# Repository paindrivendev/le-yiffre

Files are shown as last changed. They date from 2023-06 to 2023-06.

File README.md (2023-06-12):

# Le Yiffre

Le Yiffre is a modified hotswap Le Chiffre pcb as an experimental design with different thumb clusters.Thanks to tominabox1 for creating [Le Chiffre Keyboard](https://github.com/tominabox1/Le-Chiffre-Keyboard) and making it open source.

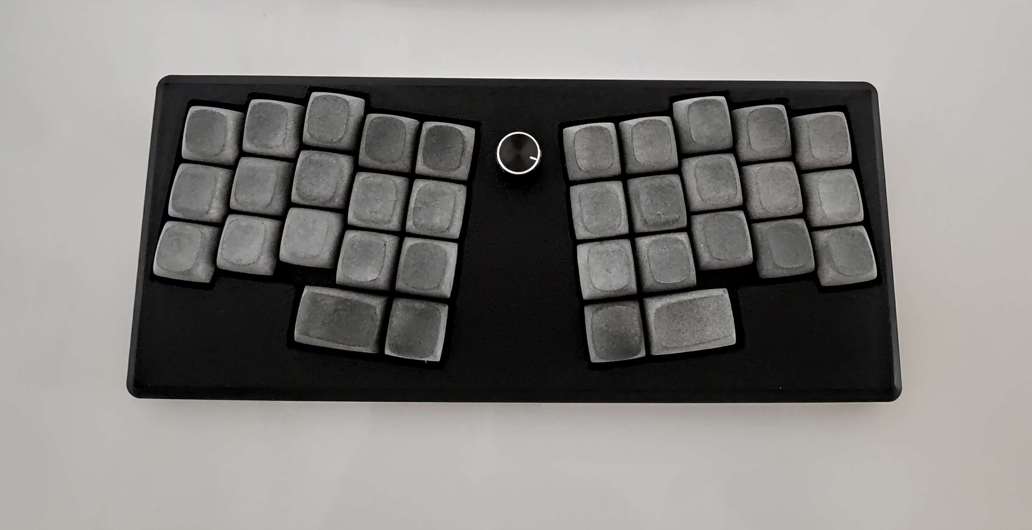
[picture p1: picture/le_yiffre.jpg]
Le Yiffre Keyboard


## Description

PCB, 3d case and switch plates tested and works fine. Building one is your own
risk.

## QMK Configuration

Works with le chiffre qmk config.

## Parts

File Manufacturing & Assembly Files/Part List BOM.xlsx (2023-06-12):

Item | Qty | Reference(s) | Value | Footprint | JLCPCB Part# | Weblink | Column1
1 | 5 | C1, C2, C4, C5, C7 | 100nf | Ahsan Libs:C_0603_1608Metric | C14663 | https://lcsc.com/product-detail/Multilayer-Ceramic-Capacitors-MLCC-SMD-SMT_YAGEO-CC0603KRX7R9BB104_C14663.html
2 | 1 | C8 | 4.7uf | Ahsan Libs:C_0603_1608Metric | C19666 | https://www.lcsc.com/product-detail/Multilayer-Ceramic-Capacitors-MLCC-SMD-SMT_Samsung-Electro-Mechanics-CL10A475KO8NNNC_C19666.html
3 | 1 | C9 | 1uf | Ahsan Libs:C_0603_1608Metric | C15849 | https://lcsc.com/product-detail/Multilayer-Ceramic-Capacitors-MLCC-SMD-SMT_Samsung-Electro-Mechanics-CL10A105KB8NNNC_C15849.html
4 | 2 | C10, C11 | 22pf | Ahsan Libs:C_0603_1608Metric | C1653 | https://lcsc.com/product-detail/Multilayer-Ceramic-Capacitors-MLCC-SMD-SMT_Samsung-Electro-Mechanics-CL10C220JB8NNNC_C1653.html
5 | 34 | D1, D2, D3, D4, D5, D6, D7, D8, D9, D10, D11, D12, D13, D14, D15, D16, D17, D18, D19, D20, D21, D22, D23, D24, D25, D26, D27, D28, D29, D30, D31, D32, D33, D34, D35 | 1N4148 | Ahsan Libs:D_SOD-123 | C81598 | https://lcsc.com/product-detail/Switching-Diode_ST-Semtech-1N4148W_C81598.html
6 | 11 | D101, D102, D103, D104, D105, D106, D107, D108, D109, D110, D111 | WS2812B | LED_SMD:LED_WS2812B_PLCC4_5.0x5.0mm_P3.2mm | C2761795 | https://www.lcsc.com/product-detail/Light-Emitting-Diodes-LED_Worldsemi-WS2812B-B-T_C2761795.html
7 | 1 | ESD2 | PRTR5V0U2X | Ahsan Libs:PRTR5V0U2X | C2827688 | https://lcsc.com/product-detail/ESD-Protection-Devices_TECH-PUBLIC-PRTR5V0U2X_C2827688.html
8 | 1 | OLED1 | Screw_Terminal_01x04 | Ahsan Libs:SSD1306-0.91-OLED-4pin-128x32 | C5116530 | https://www.lcsc.com/product-detail/Female-Headers_ZHOURI-PM2-54-1-4_C5116530.html
9 | 1 | P1 | LED | Ahsan Libs:LED_0603_1608Metric | C72041 | https://lcsc.com/product-detail/Light-Emitting-Diodes-LED_Everlight-Elec-19-217-BHC-ZL1M2RY-3T_C72041.html
10 | 2 | R7, R8 | 4.7k | Ahsan Libs:R_0603_1608Metric | C23162 | https://www.lcsc.com/product-detail/Chip-Resistor-Surface-Mount_UNI-ROYAL-Uniroyal-Elec-0603WAF4701T5E_C23162.html
11 | 2 | R11, R12 | 5.1K | Ahsan Libs:R_0603_1608Metric | C23186 | https://lcsc.com/product-detail/Chip-Resistor-Surface-Mount_UNI-ROYAL-Uniroyal-Elec-0603WAF5101T5E_C23186.html
12 | 2 | R14, R17 | 10k | Ahsan Libs:R_0603_1608Metric | C25804 | https://lcsc.com/product-detail/Chip-Resistor-Surface-Mount_UNI-ROYAL-Uniroyal-Elec-0603WAF1002T5E_C25804.html
13 | 1 | R15 | 22 | Ahsan Libs:R_0603_1608Metric | C1203 | https://lcsc.com/product-detail/Chip-Resistor-Surface-Mount_UNI-ROYAL-Uniroyal-Elec-0603WAJ0220T5E_C1203.html
14 | 1 | R16 | 22 | Ahsan Libs:R_0603_1608Metric | C1203 | https://lcsc.com/product-detail/Chip-Resistor-Surface-Mount_UNI-ROYAL-Uniroyal-Elec-0603WAJ0220T5E_C1203.html
15 | 1 | R18 | 470 | Ahsan Libs:R_0603_1608Metric | C23179 | https://lcsc.com/product-detail/Chip-Resistor-Surface-Mount_UNI-ROYAL-Uniroyal-Elec-0603WAF4700T5E_C23179.html
16 | 35 | SW2, SW3, SW4, SW5, SW6, SW7, SW8, SW9, SW10, SW11, SW12, SW13, SW14, SW15, SW16, SW17, SW18, SW19, SW20, SW21, SW22, SW23, SW24, SW25, SW26, SW27, SW28, SW29, SW30, SW31, SW32, SW33, SW34, SW35, SW37 | SW_Push | Ahsan Libs:SW_Hotswap_Kailh_1.00u_rev | C5156480 | https://lcsc.com/product-detail/Mechanical-Keyboard-Shaft_Kailh-CPG151101S11-16_C5156480.html | https://shop.keyboard.io/products/kailh-hotswap-sockets-for-mx-style-keyswitches-x-25
17 | 1 | SW36 | Rotary_Encoder_Switch | Rotary_Encoder:RotaryEncoder_Alps_EC12E-Switch_Vertical_H20mm_CircularMountingHoles | C370992 | https://www.lcsc.com/product-detail/Rotary-Encoders_ALPSALPINE-EC11E153440D_C370992.html
18 | 1 | SWR1 | SW_Push | Ahsan Libs:K2-1187SQ-A4SW-06 | C388295 | https://lcsc.com/product-detail/Tactile-Switches_SHOU-HAN-TS5215A-250gf_C388295.html
19 | 1 | U1 | ATMEGA32U4-MU | Ahsan Libs:ATMEGA32U4-MURr | C112161 | https://lcsc.com/product-detail/ATMEL-AVR_Microchip-Tech-ATMEGA32U4-MU_C112161.html
20 | 1 | USB1 | USB_C_Receptacle_USB2.0 | Ahsan Libs:USB_C_Receptacle_HRO_TYPE-C-31-M-12 | C165948 | https://www.lcsc.com/product-detail/USB-Connectors_Korean-Hroparts-Elec-TYPE-C-31-M-12_C165948.html
21 | 1 | Y2 | Crystal_GND23 | Ahsan Libs:Crystal_SMD_3225-4Pin_3.2x2.5mm | C13738 | https://lcsc.com/product-detail/Crystals_Yangxing-Tech-X322516MLB4SI_C13738.html

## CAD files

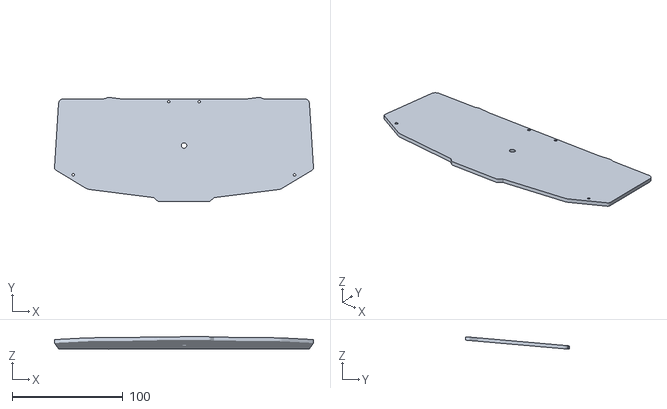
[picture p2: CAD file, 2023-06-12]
p3d_case/Le Chiffre Acylic Bottom stl.stl
234.2 x 94.2 x 11.3

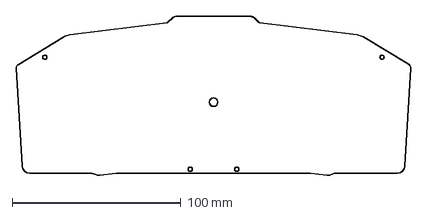
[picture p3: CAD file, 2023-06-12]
p3d_case/Acrylic Bottom Le Chiffre P3D Mod v7.dxf
234.3 x 94.4 mm

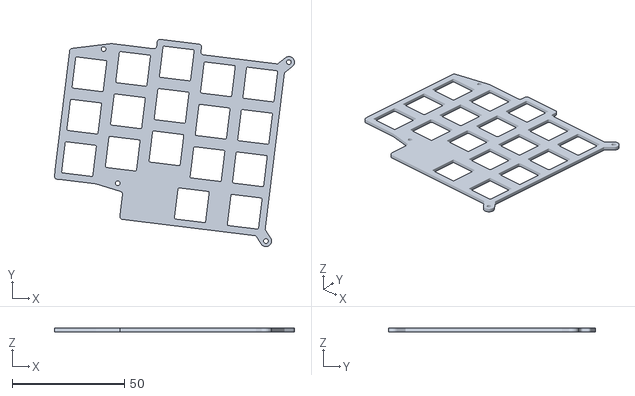
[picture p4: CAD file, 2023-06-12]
p3d_case/swtich_plate_left.stl
107.1 x 92.5 x 1.60

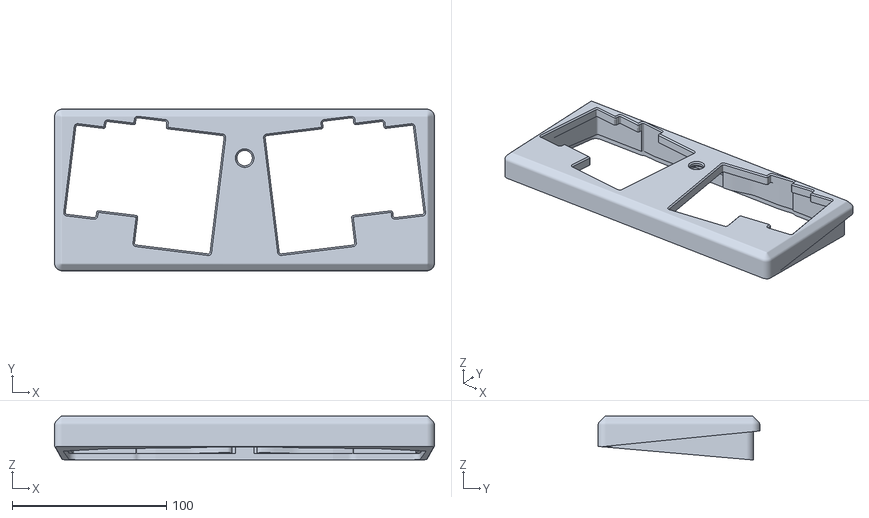
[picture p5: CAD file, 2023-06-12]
p3d_case/top_case.stl
246.4 x 104.8 x 28.5

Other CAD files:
p3d_case/switch_plate_right.stl

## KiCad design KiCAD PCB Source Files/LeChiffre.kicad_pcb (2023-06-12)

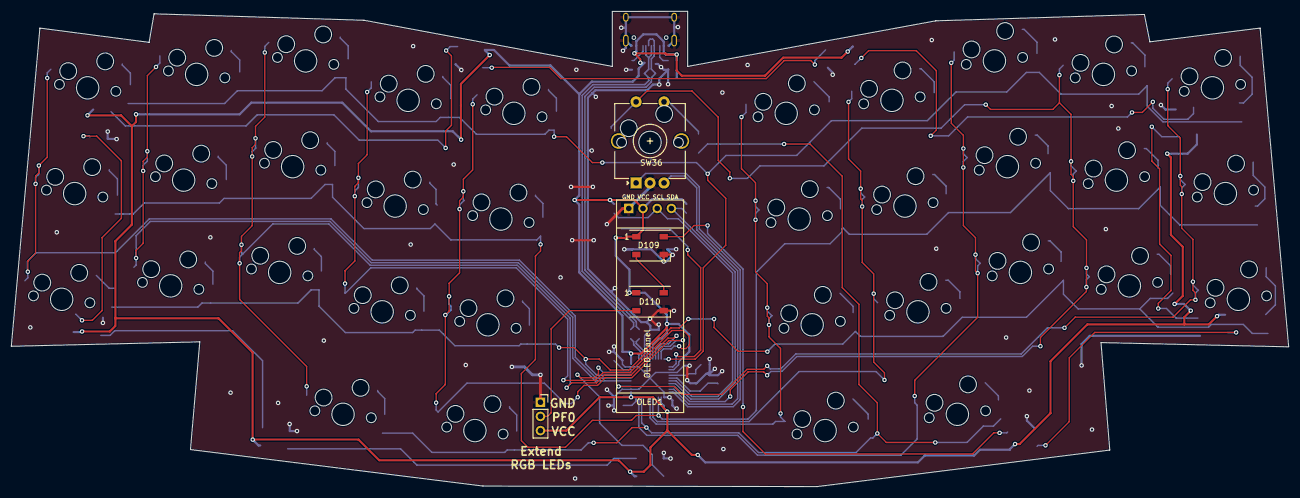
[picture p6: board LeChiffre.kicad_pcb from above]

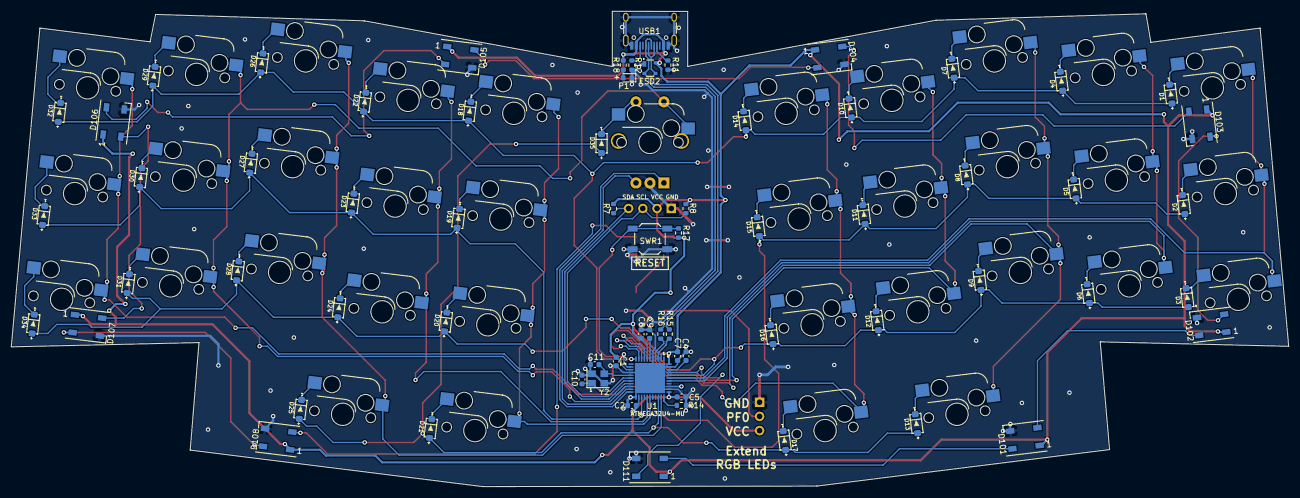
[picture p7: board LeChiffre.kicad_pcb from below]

Board: 2 copper layers, 228.4 x 85.0 mm, 108 parts (103 on the bottom side), 80 nets.

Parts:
C1, C2, C4, C5, C7: 100nf; C_0603_1608Metric
C8: 4.7uf; C_0603_1608Metric
C9: 1uf; C_0603_1608Metric
C10, C11: 22pf; C_0603_1608Metric
D1, D2, D3, D4, D5, D6, D7, D8, D9, D10, D11, D12, D13, D14, D15, D16, D17, D18, D19, D20, D21, D22, D23, D24, D25, D26, D27, D28, D29, D30, D31, D32, D33, D34, D35: 1N4148; D_SOD-123
D101, D102, D103, D104, D105, D106, D107, D108, D109, D110, D111: WS2812B; LED_WS2812B_PLCC4_5.0x5.0mm_P3.2mm
ESD2: PRTR5V0U2X
J1: Conn_01x03_Female; PinSocket_1x03_P2.54mm_Vertical
OLED1: Screw_Terminal_01x04; SSD1306-0.91-OLED-4pin-128x32
P1: LED; LED_0603_1608Metric
R7, R8: 4.7k; R_0603_1608Metric
R11, R12: 5.1K; R_0603_1608Metric
R14, R17: 10k; R_0603_1608Metric
R15, R16: 22; R_0603_1608Metric
R18: 470; R_0603_1608Metric
SW2, SW3, SW4, SW5, SW6, SW7, SW8, SW9, SW10, SW11, SW12, SW13, SW14, SW15, SW16, SW17, SW18, SW19, SW20, SW21, SW22, SW23, SW24, SW25, SW26, SW27, SW28, SW29, SW30, SW31, SW32, SW33, SW34, SW35, SW37: SW_Push; SW_Hotswap_Kailh_1.00u_rev
SW36: Rotary_Encoder_Switch; RotaryEncoder_Alps_EC12E-Switch_Vertical_H20mm_CircularMoun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
SWR1: SW_Push; K2-1187SQ-A4SW-06
U1: ATMEGA32U4-MU; ATMEGA32U4-MURr
USB1: USB_C_Receptacle_USB2.0; USB_C_Receptacle_HRO_TYPE-C-31-M-12
Y2: Crystal_GND23; Crystal_SMD_3225-4Pin_3.2x2.5mm

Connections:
+5V: C1.1, C2.1, C5.1, C7.1, C8.1, D101.1 (VDD), D102.1 (VDD), D103.1 (VDD), D104.1 (VDD), D105.1 (VDD), D106.1 (VDD), D107.1 (VDD), D108.1 (VDD), D109.1 (VDD), D110.1 (VDD), D111.1 (VDD), ESD2.4 (VCC), J1.3 (Pin_1), OLED1.2, R7.2, R8.2, R17.1, R18.2, U1.2 (UVCC), U1.7 (VBUS), U1.14 (VCC_1), U1.24 (AVCC_1), U1.34 (VCC_2), U1.44 (AVCC_2), USB1.A4 (VBUS), USB1.A9 (VBUS), USB1.B4 (VBUS), USB1.B9 (VBUS)
DN: ESD2.3 (I/O2), R15.2, USB1.A7 (D-), USB1.B7 (D-)
DP: ESD2.2 (I/O1), R16.2, USB1.A6 (D+), USB1.B6 (D+)
D_N: R15.1, U1.3 (D-)
D_P: R16.1, U1.4 (D+)
EncA: SW36.A, U1.22 ((XCK1/~CTS)_PD5)
EncB: SW36.B, U1.21 ((TXD1/INT3)_PD3)
GND: C1.2, C2.2, C4.1, C5.2, C7.2, C8.2, C9.1, C10.2, C11.2, D101.3 (VSS), D102.3 (VSS), D103.3 (VSS), D104.3 (VSS), D105.3 (VSS), D106.3 (VSS), D107.3 (VSS), D108.3 (VSS), D109.3 (VSS), D110.3 (VSS), D111.3 (VSS), ESD2.1 (GND), J1.1 (Pin_3), OLED1.1, P1.1 (K), R11.1, R12.1, R14.2, SW36.C, SWR1.1, U1.5 (UGND), U1.15 (GND_1), U1.23 (GND_2), U1.35 (GND_3), U1.43 (GND_4), U1.45 (EP), USB1.A1 (GND), USB1.A12 (GND), USB1.B1 (GND), USB1.B12 (GND), USB1.S1 (SHIELD), Y2.2, Y2.4
LED: D111.4 (DIN), U1.41 (PF0_(ADC0))
unnamed: D1.1 (K), SW2.1
unnamed: D2.1 (K), SW3.1
unnamed: D3.1 (K), SW4.1
unnamed: D4.1 (K), SW5.1
unnamed: D5.1 (K), SW6.1
unnamed: D6.1 (K), SW7.1
unnamed: D7.1 (K), SW8.1
unnamed: D8.1 (K), SW9.1
unnamed: D9.1 (K), SW10.1
unnamed: D10.1 (K), SW11.1
unnamed: D11.1 (K), SW12.1
unnamed: D12.1 (K), SW13.1
unnamed: D13.1 (K), SW14.1
unnamed: D14.1 (K), SW15.1
unnamed: D15.1 (K), SW16.1
unnamed: D16.1 (K), SW17.1
unnamed: D17.1 (K), SW18.1
unnamed: D18.1 (K), SW19.1
unnamed: D19.1 (K), SW20.1
unnamed: D20.1 (K), SW21.1
unnamed: D21.1 (K), SW22.1
unnamed: D22.1 (K), SW23.1
unnamed: D23.1 (K), SW24.1
unnamed: D24.1 (K), SW25.1
unnamed: D25.1 (K), SW26.1
unnamed: D26.1 (K), SW27.1
unnamed: D27.1 (K), SW28.1
unnamed: D28.1 (K), SW29.1
unnamed: D29.1 (K), SW30.1
unnamed: D30.1 (K), SW31.1
unnamed: D31.1 (K), SW32.1
unnamed: D32.1 (K), SW33.1
unnamed: D33.1 (K), SW34.1
unnamed: D34.1 (K), SW35.1
unnamed: D35.1 (K), SW36.S1, SW37.1
unnamed: D101.4 (DIN), D111.2 (DOUT)
unnamed: D101.2 (DOUT), D102.4 (DIN)
unnamed: D102.2 (DOUT), D103.4 (DIN)
unnamed: D103.2 (DOUT), D104.4 (DIN)
unnamed: D104.2 (DOUT), D105.4 (DIN)
unnamed: D105.2 (DOUT), D106.4 (DIN)
unnamed: D106.2 (DOUT), D107.4 (DIN)
unnamed: D107.2 (DOUT), D108.4 (DIN)
unnamed: D108.2 (DOUT), D109.4 (DIN)
unnamed: D109.2 (DOUT), D110.4 (DIN)
unnamed: D110.2 (DOUT), J1.2
unnamed: P1.2 (A), R18.1
unnamed: C4.2, U1.42 (AREF)
unnamed: R14.1, U1.33 (PE2_(H~WB))
unnamed: C9.2, U1.6 (UCAP)
unnamed: R11.2, USB1.A5 (CC1)
unnamed: R12.2, USB1.B5 (CC2)
RESET: R17.2, SWR1.2, U1.13 (~RESET)
SCK: OLED1.3, R8.1, U1.18 ((OC0B/SCL/INT0)_PD0)
SDA: OLED1.4, R7.1, U1.19 ((SDA/INT1)_PD1)
XTAL1: C10.1, U1.17 (XTAL1), Y2.1
XTAL2: C11.1, U1.16 (XTAL2), Y2.3
col0: SW2.2, SW3.2, SW4.2, U1.39 (PF4_(ADC4/TCK))
col1: SW5.2, SW6.2, SW7.2, U1.38 (PF5_(ADC5/TMS))
col2: SW8.2, SW9.2, SW10.2, SW14.2, U1.8 ((SS/PCINT0)_PB0)
col3: SW11.2, SW12.2, SW13.2, U1.10 ((PDI/PCINT2/MOSI)_PB2)
col4: SW15.2, SW16.2, SW17.2, SW18.2, U1.9 ((PCINT1/SCLK)_PB1)
col5: SW19.2, SW20.2, SW21.2, SW22.2, U1.28 (PB4_(PCINT4/ADC11))
col6: SW23.2, SW24.2, SW25.2, U1.27 (PD7_(T0/OC4D/ADC10))
col7: SW26.2, SW27.2, SW28.2, SW29.2, U1.32 (PC7_(ICP3/CLK0/OC4A))
col8: SW30.2, SW31.2, SW32.2, SW36.S2, SW37.2, U1.20 ((RXD1/INT2)_PD2)
col9: SW33.2, SW34.2, SW35.2, U1.36 (PF7_(ADC7/TDI))
row0: D1.2 (A), D4.2 (A), D7.2 (A), D10.2 (A), D14.2 (A), D18.2 (A), D22.2 (A), D26.2 (A), D29.2 (A), D32.2 (A), U1.11 ((PDO/PCINT3/MISO)_PB3)
row1: D2.2 (A), D5.2 (A), D8.2 (A), D11.2 (A), D15.2 (A), D19.2 (A), D23.2 (A), D27.2 (A), D30.2 (A), D33.2 (A), U1.25 (PD4_(ICP1/ADC8))
row2: D3.2 (A), D6.2 (A), D9.2 (A), D12.2 (A), D16.2 (A), D20.2 (A), D24.2 (A), D28.2 (A), D31.2 (A), D34.2 (A), U1.40 (PF1_(ADC1))
row3: D13.2 (A), D17.2 (A), D21.2 (A), D25.2 (A), D35.2 (A), U1.31 (PC6_(OC3A/~OC4A))
